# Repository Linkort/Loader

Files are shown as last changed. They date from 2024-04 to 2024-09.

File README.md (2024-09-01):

# Устройство для подготовки плат/модулей расширения ПЛК.
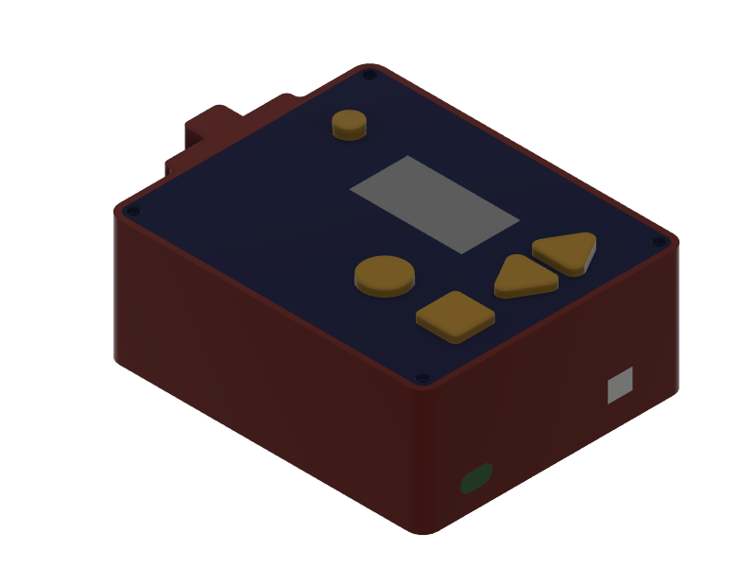
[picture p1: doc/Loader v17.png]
Loader v17

## Описание
Устройство разработано на основе Wemos D1 Mini Lite(ESP8266).
Устройство предназначено для подготовки плат/модулей расширения к работе в составе ПЛК <br> 

Loader позволяет:<br> 
- Смена Modbus адреса платы/модуля расширения ПЛК;
- Загрузка прошивки на плату/модуль на основе STM32 используя встроенный bootloader микроконтроллера.

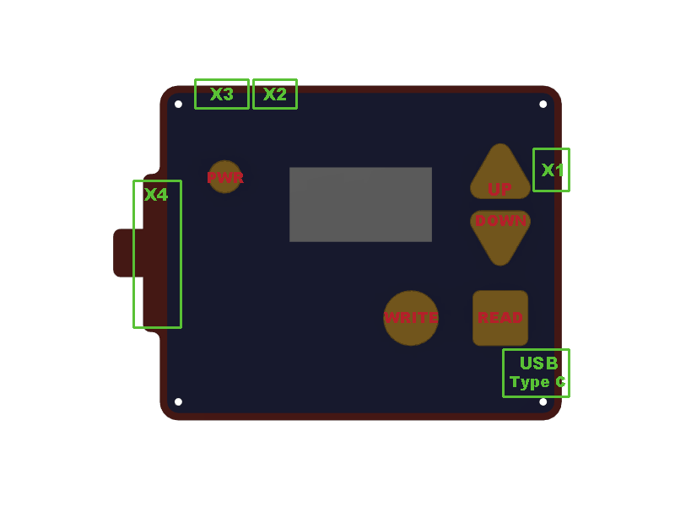
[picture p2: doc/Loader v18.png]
Loader v18
<br>
На лицевой стороне расположены дисплей и кнопки управления:    
- Кнопки UP/ DOWN - изменение значений на дисплее;<br>
- Кнопка READ - Команда на чтение;<br>
- Кнопка WRITE - Команда на запись;<br>
- Кнопка POWER - Отключение питания на плате/модуле. Рекомендуется для перезагрузки целевой платы. <br>

Разъемы подключения:<br>
- X1 - Разъем питания 9-30V DC;<br>
- X2, X3 - Разъемы подключения модуля расширения;<br>
- X4 - Разъем подключения платы расширения;<br>
- USB type C - Разъем питания / программирования.<br>
>**При питании через кабель USB type C - работа возможна только с платами расширения.**<br>
>**Одновременное подключение двух источников питания запрещено.**

## Инструкция

### Режимы работы
Loader имеет три режима работы:
  - Режим смены адреса. Текст на дисплее "Adr". Loader по протоколу Modbus RTU может прочитать / записать Modbus адрес устройства. Связь ведется с помощью broadcast адреса - 255, поддерживаемый платами/модулями расширения. Данный режим основной. Текст на дисплее "FLS". Loader по умолчанию переходит в данный режим при включении.<br>
  - Режим прошивки. Loader по протоколу USART(AN3155) записывает прошивку в микроконтроллер STM32 на плате расширения. Для перехода в данный режим необходимо зажать кнопки UP и DOWN в режиме смены адреса. Повторение действия приведет к переходу в "Режим смены адреса".<br>
  - Режим точки доступа. Текст на дисплее "AP". Необходим для загрузки в Loader прошивок для плат расширения. Для перехода в данный режим необходимо подать питание на устройство при зажатой кнопке READ или WRITE. При включении активируется точка доступа (ssid: Loader, pass: 11111111). После подключения с помощью FTP клиента можно загрузить в Loader прошивки STM32.<br>

### Смена адреса платы
1\. Подать питание на Loader.<br>
2\. Настроить плату/модуль<br>
Для платы расширения: <br>
- Установить SW1.1 - в положение ON / UP. <br>
- Установить SW1.2 - в положение OFF / DOWN<br>

Для модуля расширения: <br>
- Установить Джампер J4.<br>
- Снять Джампер J3.<br>
<details>
  <summary> Назначение переключателей</summary>
  
  |                                         | Переключатель                                  | Переключатель                            |
  | --------------------------------------- | ---------------------------------------------- | ---------------------------------------- |
  | Плата <br>Расширения                    | Джампер J4                                     | Джампер J3                               |
  | Модуль <br>расширения                   | SW1.1                                          | SW1.2                                    |
  | Назначение                              | Запись настроек в <br>энергонезависимую память | Применение  скорости <br>из памяти       |
  | Положение ON / UP<br>Джампер установлен | Разрешено                                      | Разрешено                                |
  | Положение OFF / DOWN<br>Джампер снят    | Запрещено                                      | Запрещено.<br>Скорость для обмена 115200 |
  
</details>

3\. Подключить плату/модуль<br>
Плату расширения в разъем X4. Модуль расширения в разъем X2, X3. <br>
>**Одновременное подключение платы расширения и модуля расширения не допустимо.**<br>

4\. Нажать кнопку READ - прочитать адрес платы/модуля<br>
  При успешном чтении - на дисплее отобразится текущий адрес платы/модуля. <br>
  
5\. Изменить адрес на дисплее устройства на требуемый.<br>

6\. Нажать кнопку WRITE - записать адрес в плату расширения<br>
Сообщение "Suc" сообщает об успешном изменении адреса.

### Прошивка платы
1\. Подать питание на Loader.<br>
2\. Переключиться в режим прошивки: нажать одновременно кнопки UP и DOWN.<br>
3\. Подключить плату/модуль<br>
4\. Замкнуть джампер boot(J1) на плате/модуле. Нажать кратковременно кнопку RWR на устройстве. Можно снять джампер. В режиме прошивки на платах расширения индикатор связи будет гореть постоянно. Иначе - повторить операцию.<br>
5\. Выбрать на дисплее Loader'a нужную прошивку и нажать WRITE. Сообщение "Suc" сообщает об успешной прошивке.<br>

### Индикация на дисплее
| Индикация на дисплее | Расшифровка |
| --- | --- |
| "8.8.8." | Процедура включения устройства |
| "---" | Устройство готово к работе |
| "Adr" | Loader в режиме смены адреса |
| "FLS" | Loader в режиме прошивки плат расширения |
| "AP" | Loader в режиме точки доступа |
<details>
  <summary>Перечень ошибок на дисплее</summary>

| Индикация | Режим смены адреса | Режим прошивки |
| --- | --- | --- |
| "Er0" | Таймаут, нет ответа от устройства. | - |
| "Er1" | Принятый код функции не может быть обработан. | Ошибка файла прошивки |
| "Er2" | Регистр данных, указанный в запросе, недоступен. | Ошибка при подключении к STM32  |
| "Er3" | Значение, содержащееся в поле данных запроса, является недопустимой величиной. | Неудалось очистить память STM32 |
| "Er4" | Невосстанавливаемая ошибка, slave не смог выполнить затребованное действие. | Ошибка при записи прошивки |
| "Er5" | Адрес устройства в ответе не соответствует ожидаемому. | - |
| "Er6" | Код функции в ответе не соответствует коду запроса. | - |
| "Er7" | Ошибка CRC в ответе. | - |

</details>

## Подготовка к работе
1\. Используя Platformio загрузить ППО на ESP8266.<br>
2\. Включить Loader в режиме точки доступа. Подать питание с зажатой кнопкой READ / WRITE.<br>
3\. Loader активирует точку доступа (ssid: Loader, pass: 11111111).<br>
4\. Используя FTP клиент загрузить на устройство прошивки.<br>

## Дополнительно

<details>
  <summary>Карта регистров</summary>

Запись/Чтение происходит согласно карте регистров плат расширения:
| Адрес<br>Modbus | Описание | Кнопка READ | Кнопка WRITE |
| --- | --- | --- | --- |
| 1 | Modbus-адрес платы | Чтение и вывод на дисплей | Запись значения с дисплея |
| 2 | Делитель скорости коммуникационного порта | - | Запись фиксированного делителя - 240 |

Функция 0x03 Read Holding Registers(4x). Настройки подключения: 115200 8N1.
</details>

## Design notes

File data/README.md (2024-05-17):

Назначение файлов FTP сервера:
- index.html - Web страница;
- README.md - Файл инструкции и правил;
- *.bin - файл прошивки для плат расширения.

Файлы находящиеся в папке "/data" тек. репозитория переместить в Loader при 1 включении.

Правила прошивок:
- Наименование файла прошивки(учитывая расширение) должно состоять из: 
    - минимум из 3 символа (т.к. дисплей Loader - 3х-знаковый);
    - максимум из 31 символа (ограничение ESP8266);
- Наименование файла должно состоять из след. символов:
    - цифры 0123456789;
    - Буквы ACEFHJLPSUY;
    - Буквы bcdehnotur;
    - Символы "-"(тире), " "(пробел), "."(точка), "8."(вкл. все сегменты); 

Рекомендуется 3 символа.

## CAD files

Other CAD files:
etc/Loader v17.f3d

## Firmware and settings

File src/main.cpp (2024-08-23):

#include "main.h"

Button btnUp(BTN1);
Button btnDown(BTN2);
Button btnRead(BTN3);
Button btnWrite(BTN4);
VirtButton btnChMode;

uint8_t screenVal; //Адрес платы на экране. Значение 1-255;
uint8_t mode; // Тек. режим работы.
uint8_t firmVal; //Для отображения названий прошивок. Индекс прошивки в векторе.
std::vector <String> List; //Список прошивок

SoftwareSerial Ch(RX, TX); //порт подключения плат расширения

void setup() {
  Serial.begin(BAUDS);
  Serial.printf("\n");
  ftpSetup(); 
  if (btnRead.read() or btnWrite.read()) {
    //Переход режим точки доступа
    display(" ", "A", "P");
    Serial.println("Режим точки доступа");
    httpSetup();
    mode = 11;
    return;
  }

  //Настройки
  display("allon", "allon", "allon");
  Ch.begin(BAUDS, SWSERIAL_8N1);
  mdbSetup(Ch);
  delay(500);
  display("-", "-", "-");
}

void loop() {
  if (mode == 11) {// Режим точки доступа
    AccessPointMode();
    return;
  }

  //Обработка кнопок
  btnUp.tick();
  btnDown.tick();
  btnRead.tick();
  btnWrite.tick();
  btnChMode.tick(btnUp, btnDown); //Виртуальная кнопка для смены режима UP+DOWN

  //Cмена режима при удержании кнопок UP и DOWN. Исполнение 1 раз при смене.
  if (btnChMode.hold()){
    mode = (mode+1) % 2;
    if (mode == 0) {//Режим смены адреса платы
      display("A", "d", "r");
      mdbSetup(Ch);
      Serial.println("Режим смены адреса платы");
    }
    
    if (mode == 1) {//Режим прошивки плат
      display("F", "L", "S");
      flashSetup(Ch);
      Serial.println("Режим прошивки плат");
      List = firmwareListUpdate();  
    }
  }

  switch (mode)
  {
    case 0: //Режим смены адреса платы
      ChangeAddrMode();
      break; 
    case 1: //Режим прошивки плат
      FlashMode();
      break;
  }
  
}


void AccessPointMode(){
  /*
  Режим точки доступа.
  Вход - При подаче питания удерживать кнопку READ или WRITE.
  Выход - отключить питание.
  Назначение - работа с файлами по FTP, работа с Loader'ом по Web странице.
  */
  httpClient();
  ftpClient();
}

void FlashMode(){
  /*
  //Режим прошивки платы расширения.
  Вход - Удерживать 2 сек кнопки UP и DOWN.
  Выход - Удерживать 2 сек кнопки UP и DOWN.
  Назначение - Прошивка микроконтроллера STM32, который установлен на платах расширения.
  */

  uint8_t flashErrCode; //Результат прошивки

  //Up Button press
  if (btnUp.click() or btnUp.step()) {
    firmVal++;
    if (firmVal >= List.size()) firmVal = 0; // Защита от выхода за пределы 0-кол-во прошивок
    display(List[firmVal]);
  }

  //Down Button press
  if (btnDown.click() or btnDown.step()) {
    firmVal--;
    if (firmVal >= List.size()) firmVal = (List.size()-1); // Защита от выхода за пределы 0-кол-во прошивок
    display(List[firmVal]);
  }

  if (btnRead.click()){
    Serial.print(Ch.read());
  }

  //Write Button press
  flashErrCode = flash(btnWrite.click(), List[firmVal]);
  if (flashErrCode == 255) return;
  Serial.printf("Резульат прошивки: %u\n", flashErrCode);  
  if (flashErrCode == 200) {
    display("S","u","c"); // Вывод сообщения
    return;
  }
  display("E", "r", String(flashErrCode / 10)); // Вывод кода ошибки
}


void ChangeAddrMode() {
  /*
  //Режим смены Modbus адреса платы
  Вход - Удерживать 2 сек кнопки UP и DOWN.
  Выход - Удерживать 2 сек кнопки UP и DOWN.
  Назначение - , который установлен на платах расширения.
  */

  uint8_t mdbErrCode; //Результат чтения/записи по Modbus

  //Up Button press
  if (btnUp.click() or btnUp.step()) {
    screenVal++;
    if (screenVal == 0) screenVal = 1;  //Защита от 0 значения
    display(screenVal);
  }

  //Down Button press
  if (btnDown.click() or btnDown.step()) {
    screenVal--;
    if (screenVal == 0) screenVal = 255;  //Защита от 0 значения
    display(screenVal);
  }

  //Работа с Modbus устройством
  mdbErrCode = mdbPoll(btnRead.click(), btnWrite.click(), screenVal); 
  if (mdbErrCode == 255) return; //Не было команды
  Serial.printf("Резульат запроса: %u\n", mdbErrCode);  
  if (mdbErrCode == 108) { //Успешное чтение
    display(screenVal); // Вывод адреса платы
    return;
  }
  if (mdbErrCode == 109) { //Успешная запись
    display("S","u","c"); // Вывод сообщения
    return;
  }
  display("E", "r", String(mdbErrCode % 10)); // Вывод кода ошибки
}

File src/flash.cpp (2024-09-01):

#include "flash.h"


File UploadFile; //Файл прошивки

SoftwareSerial *Sport;

void flashSetup(SoftwareSerial &p){
    Sport = &p;
    //Переоткрыть порт с новыми параметрами
    (*Sport).end();
    (*Sport).begin(FlashBauds, SWSERIAL_8E1);
}

uint8_t flash(bool cmd, String fileName){
    uint8_t result = 255;
    if (!cmd) return result; //Выход при отсутствии команды
    
    while ((*Sport).available()) (*Sport).read(); //Очистка входного буфера
    if (!stm32Connect(result)) return result; //Подключение
    Serial.println("Init -OK-");
    
    //Подготовка файла только после подключения к STM
    String path = "/" + fileName;
    if (!SPIFFS.exists(path)) return 11; //Файл не найден.
    UploadFile = SPIFFS.open(path, "r");//Открыть файл на чтение.
    if (!UploadFile) return 12; //Ошибка при открытии файла.
    if (UploadFile.size() == 0) return 13; //Защита от пустого файла
    Serial.println("Firmware -OK-");
    
    if (!stm32ExErase(result)) return result; //Очистка памяти
    Serial.println("Erase -OK-");
    
    if (!stm32Write(UploadFile, result)) return result; //Запись Прошивки
    Serial.println("Write -OK-");

    UploadFile.close(); //Закрыть файл.
    return 200;
    /* result cases:
        255 - Нет команды на прошивку.
        11 - Файл не найден.
        12 - Ошибка при открытии файла.
        13 - Файл прошивки пуст.

        21 - Подключение. Нет ответа от платы.
        22 - Подключение. STM32 вернул NACT ответ при попытке подключения. 
        23 - Подключение. STM32 вернул не ожидаемый фрейм.

        31 - Очистка памяти. Нет ответа от платы после отправки команды.
        32 - Очистка памяти. STM32 вернул NACT ответ после отправки команды. Команда не поддерживается
        33 - Очистка памяти. STM32 вернул не ожидаемый фрейм после отправки команды.
        35 - Очистка памяти. Нет ответа от платы по завершению очистки.
        36 - Очистка памяти. STM32 вернул NACT ответ по завершению очистки. Ошибка.
        37 - Очистка памяти. STM32 вернул не ожидаемый фрейм по завершению очистки.

        41 - Запись Прошивки. Нет ответа от платы после отправки команды.
        42 - Запись Прошивки. STM32 вернул NACT ответ после отправки команды. Команда не поддерживается
        43 - Запись Прошивки. STM32 вернул не ожидаемый фрейм после отправки команды.
        44 - Запись Прошивки  Нет ответа от платы поcле отправки адреса в памяти.
        45 - Запись Прошивки. STM32 вернул NACT ответ поcле отправки адреса в памяти. Ошибка CRC.
        46 - Запись Прошивки. STM32 вернул не ожидаемый фрейм поcле отправки адреса в памяти.
        47 - Запись Прошивки  Нет ответа от платы поcле отправки данных.
        48 - Запись Прошивки. STM32 вернул NACT ответ поcле отправки данных. Ошибка CRC.
        49 - Запись Прошивки. STM32 вернул не ожидаемый фрейм поcле отправки данных.

        120 - Подключение успешно
        130 - Команда очистки 0x44 Поддерживается
        134 - Очистка Памяти прошла успешно
        200 - Успешная загрузка прошивки
    */
}

bool stm32Connect(uint8_t& err){
    Sport->write(STM32INIT);
    if (!checkAct(20, err)) return false; //Проверка ответного фрейма
    return true; //Ошибка
}

bool checkAct(uint8_t errtype, uint8_t& err){
    byte buf[1];//ответ
    if (!(*Sport).readBytes(buf, 1)){//Таймаут
        err = errtype + 1;
        return false;
    }

    switch (buf[0]){
        case STM32ACT: //Ответ Успешный
            err = errtype + 100;
            delay(50); //костыль, иначе след команда не обрабат. STM32. ?
            return true;
            break;
        case STM32NACT: // Ответ отриц. Команда не поддерживается
            err = errtype + 2;
            break;
        default: // Неожидаемый фрейм
            err = errtype + 3;
            break;
    }
    return false;
}

void sendCmd(byte cmd){
    //Для каждой команды хост отправляет байт и его байт-инверсия
    Sport->write(cmd);
    Sport->write(~cmd); 
}

uint8_t CRC(const uint8_t (&buf)[], size_t cnt){
    uint8_t crc = 0x00;
    for (size_t i = 0; i < cnt; i++)
    {
        crc ^= buf[i];
    }
    return crc;
}

bool stm32Write(File& firmware, uint8_t& err){
    uint32_t addr;
    size_t fsize = firmware.size(); //Размер файла
    uint16_t packlen;
    uint8_t buf[256], crc;
    
    Serial.printf("Firmware size: %u bytes.\n", fsize);
    for (uint i = 0; i < fsize;)
    {
        //Запись идет пакетами по 256 байт, последний по остатку.
        //определение длины след пакета.
        packlen = (fsize - i);
        if (packlen >= 256) packlen = 256;
        addr = FlashAddrOffset + i;
        i+= 256;
        sendCmd(STM32WRITE);
        if (!checkAct(40, err)) return false; //ожид. подтверждения
        //Адрес + CRC
        buf[0] = (addr >> 24) & 0xFF;
        buf[1] = (addr >> 16) & 0xFF;
        buf[2] = (addr >> 8) & 0xFF;
        buf[3] = (addr ) & 0xFF;
        buf[4] = CRC(buf, 4);
        (*Sport).write(buf, 5);
        if (!checkAct(43, err)) return false; //ожид. подтверждения
        //данные
        firmware.read(buf, packlen);
        crc = CRC(buf, packlen) ^ (packlen-1);
        (*Sport).write(packlen-1);
        (*Sport).write(buf, packlen);
        (*Sport).write(crc);
        if (!checkAct(46, err)) return false; //ожид. подтверждения
    }
    
    return true;
}

bool stm32ExErase(uint8_t& err){
    sendCmd(STM32EXTERASE);
    if (!checkAct(30, err)) return false; //ожид. подтверждения
    //Команда на Global Erase + байт CRC(через XOR)
    (*Sport).write(0xFF); 
    (*Sport).write(0xFF); 
    (*Sport).write(0x00); 
    if (!checkAct(34, err)) return false; //ожид. подтверждения очистки
    return true;
}

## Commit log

2024-03-10 Добавлен функционал работы с платой расширения - чтение адреса платы по Modbus RTU - запись адреса, делителя скорости платы по Modbus RTU:
2024-04-25 Добавлена схема, корпус. Мелкие правки. - Добавлен электрическая схема; - Добавлен проект корпуса; - Увеличена скорость прироста адреса при удержании UP/DOWN; - Изменены входа подключения конопок упр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
    [Loader v17.f3d]
2024-05-03 Смена режимов работы, FTP сервер, Точка доступа. - При удержании кнопок UP+DOWN: происходит цикл. смена режимов: Режим смены адреса платы | Режим прошивки плат | Режим точки доступа. - Добавлен режим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
2024-05-08 Изменен переход в режим точки доступа. - Для активации точки доступа - включить Loader при зажатой кнопке Read или Write. Выход - отключить питание. - При зажатии кнопок UP + DOWN - переход м/у режим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
2024-05-17 Организация смены режимов. Добавлен вывод названий загруженных прошивок. Мелкие правки.
2024-05-21 Работа над протоколом AN3155. -1-
2024-05-23 Работа с портом подключения плат расширения
2024-08-13 Работа над протоколом AN3155. -2-
2024-08-21 Работа над протоколом AN3155. -3-
2024-08-23 Работа над протоколом AN3155. -4-
2024-09-01 Добавление режима прошивки, корректировка ReadMe.md - Завершена разработка режима прошивки плат расширения - Ускорена скорость загрузки прошивки до 128000 бод. - Корректировка ReadMe.md.
